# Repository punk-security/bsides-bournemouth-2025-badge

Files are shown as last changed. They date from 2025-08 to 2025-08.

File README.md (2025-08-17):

# BSides Bournemouth (2025) Skull badge

This badge uses UV full colour silk, and we ordered them from JLCPCB using EasyEDA. The PCB was built first with AutoCAD EAGLE, then exported.

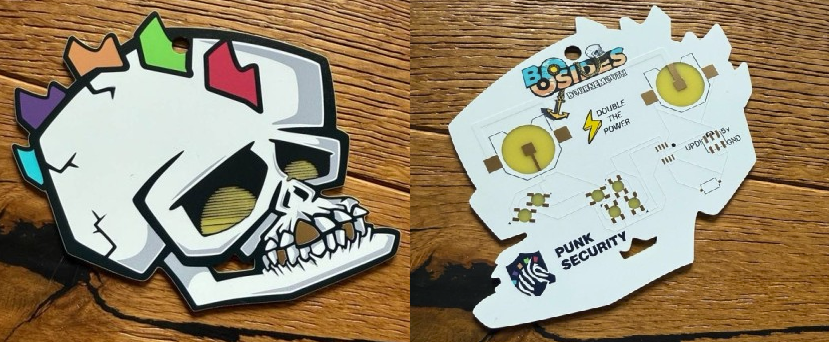
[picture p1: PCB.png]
PCB


Lots of things in this repo:

- eagle-files: all the stuff you need to tinker and modify the PCB
- gerber-files.zip: the file you can upload to JLCPCB and order your own badge, as is
- bsides-bournemouth-2025-badge.ino: the arduino code that powers the badge, which you can modify and flash via the SAO connector
- skull.svg: the original vector design for the badge
- skull.png: the silkscreen as ordered

## Bill Of Materials

You can see a parts list on DigiKey [here](https://www.digikey.co.uk/en/mylists/list/Z9CH9C1GM3). This is the list for the BSIDES Cheltenham 2024 badge, but it is the same bits.

Essentially its:

* ATTINY402 microcontroller
* Button - any surface mount button fitting the footprint will work
* CR2032 battery clip x 2 - surface mount not through hole
* Neopixel 5050 addressable LED - Definitely get the right version of these

## Eagle designs and ordering your own badge

We've uploaded the AutoCAD EAGLE schematic and board design!  You will probably have to do some tweaks to get it working as they're not designed to be standalone exports.

We've also uploaded the gerber_files.zip.  Take this to JLCPCB and you can order your own exact copies of the board :)

## Writing and flashing code!

We use [MegaTinyCore](https://github.com/SpenceKonde/megaTinyCore) for the arduino interface for ATTINY4x2 chips.

Dev and flashing is done within the Arduino IDE ( < v2 ) using a jtag2updi interface, as discussed [here](https://github.com/SpenceKonde/AVR-Guidance/blob/master/UPDI/jtag2updi.md)

We use [these little usb sticks](https://amzn.eu/d/c0lx0wG), with a 4.7k resistor soldered between the Tx and Rx lines.  

### Installing MegaTinyCore dependencies

This board package can be installed via the board manager in arduino. The boards manager URL is:

`http://drazzy.com/package_drazzy.com_index.json`

1. File -> Preferences, enter the above URL in "Additional Boards Manager URLs"
2. Tools -> Boards -> Boards Manager...
3. Wait while the list loads (takes longer than one would expect, and refreshes several times).
4. Select "megaTinyCore by Spence Konde" and click "Install". For best results, choose the most recent version.

### Setting up the IDE

1. Open the file **bsides-cheltenham-2024-badge.ino** in arduino
2. Select tools > Board > megaTinyCore > ATtiny412/402/212/202
3. Select tools > Chip > ATtiny402
4. Select tools > Clock > 8Mhz internal *(we get power issues otherwise)*
5. Select tools > Programmer > SerialUPDI SLOW
6. Select tools > Port > ( pick your COM port)

### Flashing firmware
1. Connect the 3v3 pin to 3v on your usb (maybe wedge it in the battery clip)
2. Connect GND to GND
3. Connect UPDI to the RxD port
4. Click Upload button

## How to solder?

Make sure to line up the dot on the attiny402 with the dot on the board.

Make sure to line the corner of the LED with the cutout with the triable on the board

*It's much easier if you hold the component in place with one hand, and then solder one pad. Now you can solder the rest of the pads with one hand*

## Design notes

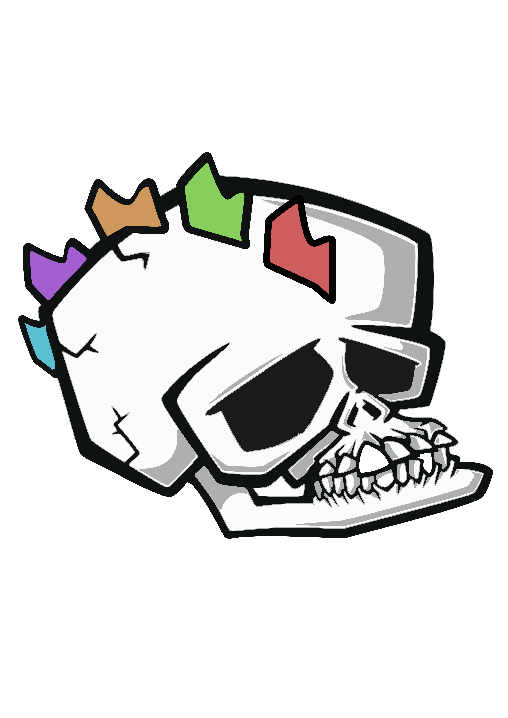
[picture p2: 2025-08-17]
skull.png

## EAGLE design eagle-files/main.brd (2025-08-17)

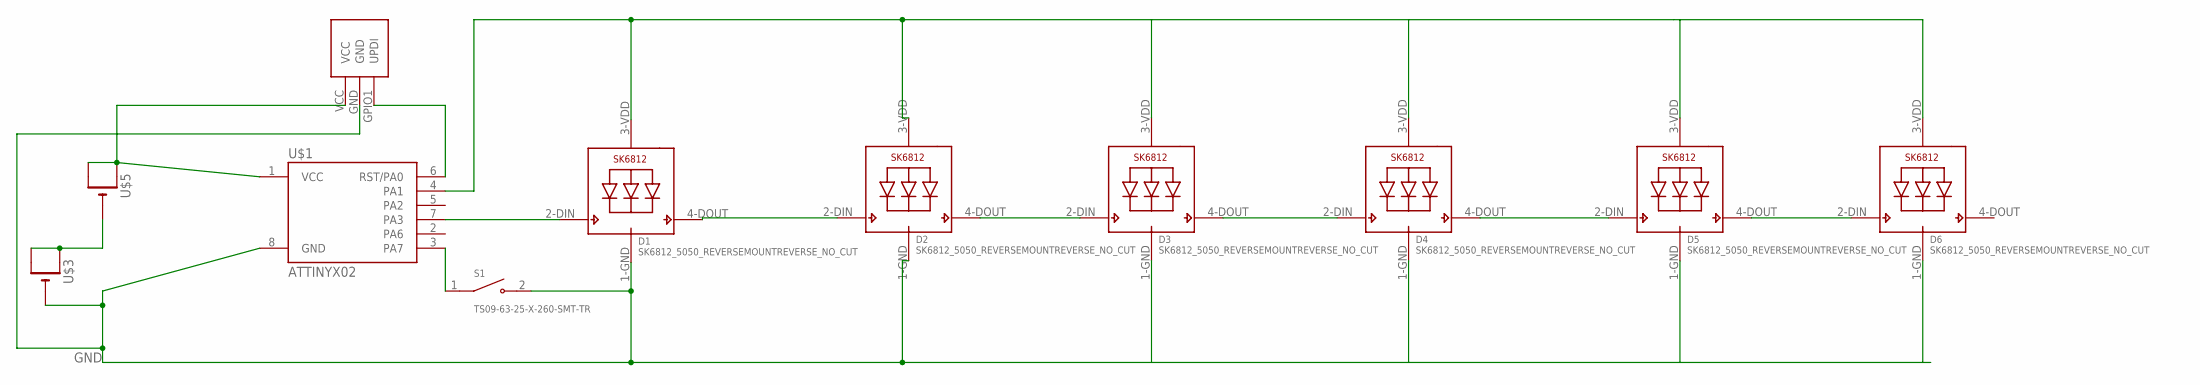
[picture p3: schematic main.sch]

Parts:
D1, D2, D3, D4, D5, D6: SK6812_5050_REVERSEMOUNTREVERSE_NO_CUT; SK6812_REVERSE_NO_CUT
S1: TS09-63-25-X-260-SMT-TR; SW_TS09-63-25-X-260-SMT-TR
U$1: ATTINYX02; SOIC08_JEDEC_150MIL
U$2: SAO; SAO_SMD
U$3, U$5: CR2032SMT; CR2032-SMD

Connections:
GND: D1.1-GND (GND), D2.1-GND (GND), D3.1-GND (GND), D4.1-GND (GND), D5.1-GND (GND), D6.1-GND (GND), S1.2, U$1.8 (GND), U$2.GND, U$3.-
unnamed: D1.4-DOUT (DO), D2.2-DIN (DI)
unnamed: D1.2-DIN (DI), U$1.7 (PA3)
unnamed: D3.4-DOUT (DO), D4.2-DIN (DI)
unnamed: D2.4-DOUT (DO), D3.2-DIN (DI)
unnamed: S1.1, U$1.3 (PA7)
unnamed: D4.4-DOUT (DO), D5.2-DIN (DI)
unnamed: D5.4-DOUT (DO), D6.2-DIN (DI)
unnamed: U$3.+$1 (+), U$3.+$2 (+1), U$5.-
unnamed: U$1.6 (RST/PA0), U$2.GPIO1 (UPDI)
VCC1: U$1.1 (VCC), U$2.VCC, U$5.+$1 (+), U$5.+$2 (+1)
VDD1: D1.3-VDD (VDD), D2.3-VDD (VDD), D3.3-VDD (VDD), D4.3-VDD (VDD), D5.3-VDD (VDD), D6.3-VDD (VDD), U$1.4 (PA1)

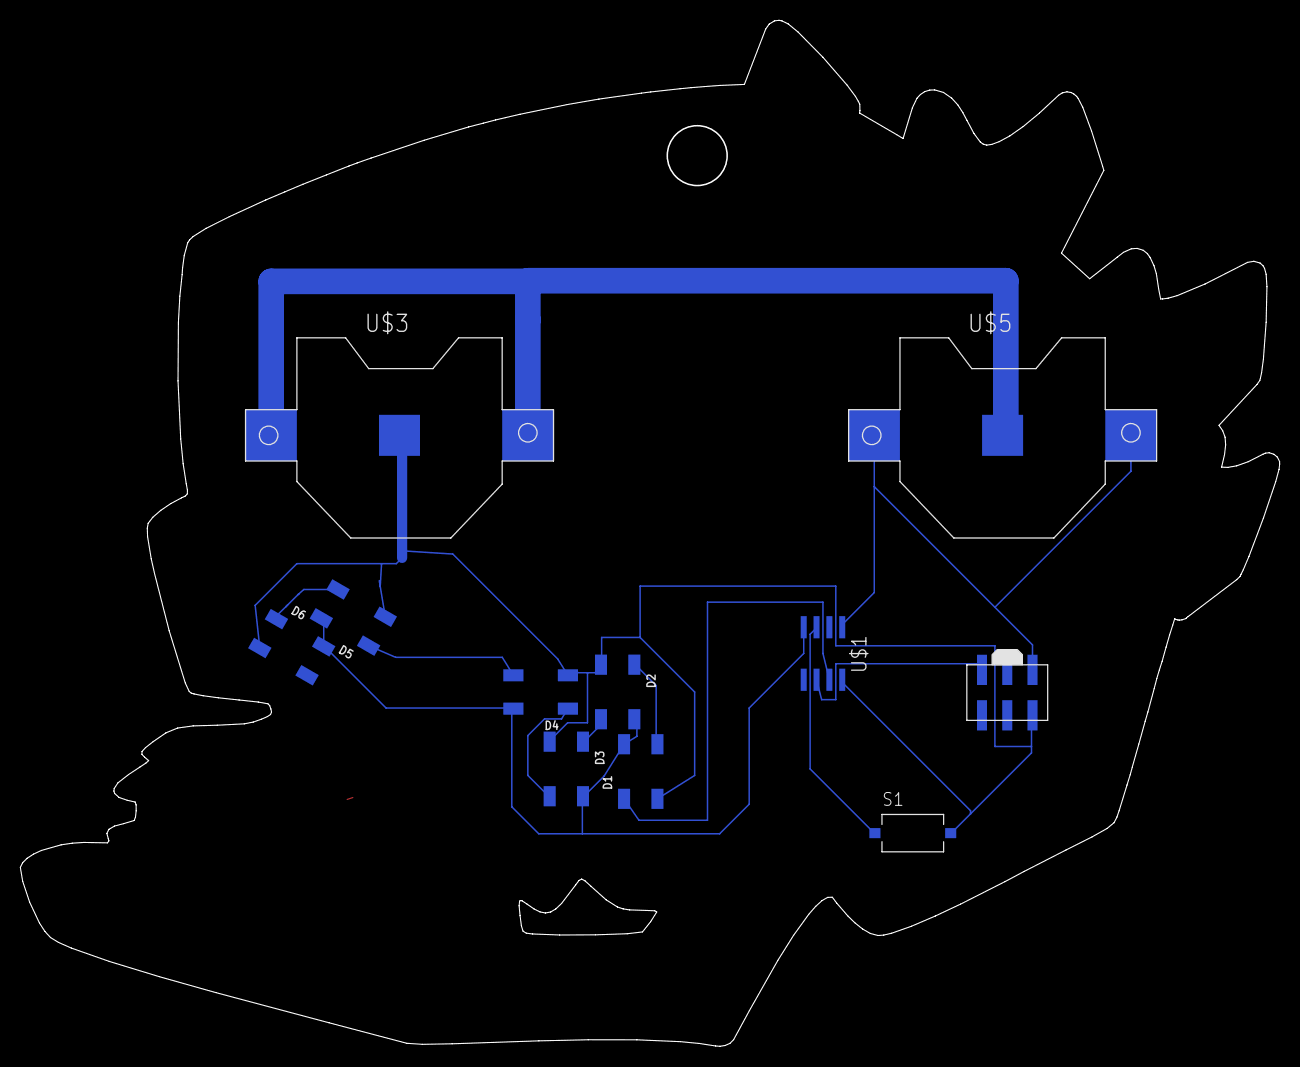
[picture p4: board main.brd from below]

Board: 2 copper layers, 124.6 x 101.5 mm, 11 parts (11 on the bottom side), 12 nets.

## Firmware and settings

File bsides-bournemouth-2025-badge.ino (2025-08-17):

#include <avr/io.h>-
#include <avr/pgmspace.h>
#include <EEPROM.h>
#include <tinyNeoPixel_Static.h>

// FEEL FREE TO TWEAK

// Wake time
# define WAKE_TIME_MS 300000
// Colours

#define OFF 0,0,0
#define BLUE 0,0,255
#define PINK 6,0,4
#define OLIVE 2,2,0
#define YELLOWGREEN 20,30,20
#define RED 50,0,0
#define ORANGE 50,30,0
#define YELLOW 30,50,0
#define GREEN 0,50,0
#define BLUE 0,0,255
#define PURPLE 10,0,128
#define BB_BLUE 0,100,255
#define BB_SAND 194,178,128

// DONT CHANGE
#define NUMLEDS 6
#define MORSE_CODE_PIN PIN_PA7
// LED positions
#define LT 1
#define LL 0
#define LB 2
#define LR 3
#define RL 4
#define RR 5

byte pixels[NUMLEDS * 3];
tinyNeoPixel strip = tinyNeoPixel(NUMLEDS, PIN_PA3, NEO_GRB, pixels);

uint16_t time_pin_low(uint16_t max_ms)
{
  // blocking for up to max_ms
  if (digitalRead(MORSE_CODE_PIN) == HIGH)
  {
    return(0);
  }
  delay(50); //debounce-
  uint16_t t = 50;
  while(digitalRead(MORSE_CODE_PIN) == LOW)
  {
    delay(5);
    t = t + 5;
    if ( t > max_ms )
      return(max_ms);
  }
  return(t);
}

void setAllPixels(int r, int g, int b, bool show = false)
{
  for (int i = 0; i < NUMLEDS; i++) 
  {
    strip.setPixelColor(i,r,g,b);
  }
  if(show)
    strip.show();
}

int fill(int x, int r, int g, int b)
{
  int step = x % 6;
  switch(step)
  {
    case 0:
      strip.setPixelColor(RR, r,g,b);
      break;
    case 1:
      strip.setPixelColor(RL, r,g,b);
      break;
    case 2:
      strip.setPixelColor(LR, r,g,b);
      break;
    case 3:
      strip.setPixelColor(LB, r,g,b);
      break;
    case 4:
      strip.setPixelColor(LT, r,g,b);
      break;
    case 5:
      strip.setPixelColor(LL, r,g,b);
      break;
    default:
      break;
  }
  strip.show();
  return 100;
}

#include <avr/sleep.h>

void sleep()
{
  set_sleep_mode(SLEEP_MODE_PWR_DOWN);
  PORTA.PIN7CTRL = PORT_PULLUPEN_bm | PORT_ISC_LEVEL_gc; // enable pullup and interrupt
  digitalWrite(PIN_PA1, LOW); // turn off LED power rail
  sleep_enable();
  sleep_cpu();
  // sleep resumes here
  PORTA.PIN7CTRL = PORT_PULLUPEN_bm; // renable pullup but no interrupt
  digitalWrite(PIN_PA1, HIGH);  // turn on LED power rail
}

ISR(PORTA_PORT_vect) {
  PORTA.INTFLAGS = PORT_INT7_bm; // Clear Pin 7 interrupt flag otherwise keep coming back here
}

uint8_t state;

void setup()
{
  // Power save
  // http://www.technoblogy.com/show?2RA3
  // https://github.com/SpenceKonde/megaTinyCore/blob/master/megaavr/extras/PowerSave.md
  ADC0.CTRLA &= ~ADC_ENABLE_bm; // Disable ADC
  pinMode(PIN_PA1, OUTPUT);
  pinMode(PIN_PA2, OUTPUT);
  pinMode(PIN_PA6, OUTPUT);
  // UPDI does not need setting (PA0)

  // Pin setup
  pinMode(PIN_PA3, OUTPUT);
  pinMode(PIN_PA7, INPUT_PULLUP);
  digitalWrite(PIN_PA1, HIGH);

  
  state = EEPROM.read(0);
  if (state == B11111111)
  {
    EEPROM.update(0, 0);
    state = EEPROM.read(0);
  }
  
}

int circle(int x, int r, int g, int b)
{
  int i = x % 7;
  setAllPixels(OFF);
  switch(i) {
   case 0:
    strip.setPixelColor(LB, OFF);
    strip.setPixelColor(LL, r, g, b);
    break;
   case 1:
    strip.setPixelColor(LL, OFF);
    strip.setPixelColor(LT, r, g, b);
    break;
   case 2:
    strip.setPixelColor(LT, OFF);
    strip.setPixelColor(RL, r, g, b);
    break;
   case 3:
    strip.setPixelColor(RL, OFF);
    strip.setPixelColor(RR, r, g, b);
    break;
   case 4:
    strip.setPixelColor(RR, OFF);
    strip.setPixelColor(RL, r, g, b);
    break;
   case 5:
    strip.setPixelColor(RL, OFF);
    strip.setPixelColor(LR, r, g, b);
    break;
   case 6:
    strip.setPixelColor(LR, OFF);
    strip.setPixelColor(LB, r, g, b);
    break;
  }
  strip.show();
  return 100;
}

int random_cycle(int n)
{
  int i = random(0,6);
  switch(i) {
   case 0:
    setAllPixels(RED,true);
    break;
   case 1:
    setAllPixels(ORANGE,true);
    break;
   case 2:
    setAllPixels(YELLOW,true);
    break;
   case 3:
    setAllPixels(GREEN,true);
    break;
   case 4:
    setAllPixels(BLUE,true);
    break;
   case 5:
    setAllPixels(PURPLE,true);
    break;
  }
  return 150;
}

int cycle(int n)
{
  int i = n % 5;
  switch(i) {
   case 0:
    setAllPixels(RED,true);
    break;
   case 1:
    setAllPixels(GREEN,true);
    break;
   case 2:
    setAllPixels(ORANGE,true);
    break;
   case 3:
    setAllPixels(PURPLE,true);
    break;
   case 4:
    setAllPixels(BLUE,true);
    break;
  }
  return 300;
}

int bournemouth(int n)
{
  int i = n % 9;
  setAllPixels(BB_SAND);

  if (i == 1)
  {
    strip.setPixelColor(LT, BB_BLUE);
  }
    else if (i == 2)
  {
    strip.setPixelColor(LT, BB_BLUE);
    strip.setPixelColor(LL, BB_BLUE);
    strip.setPixelColor(LR, BB_BLUE);
  }
    else if (i == 3 || i == 4)
  {
    strip.setPixelColor(LT, BB_BLUE);
    strip.setPixelColor(LL, BB_BLUE);
    strip.setPixelColor(LR, BB_BLUE);
    strip.setPixelColor(RL, BB_BLUE);
    strip.setPixelColor(LB, BB_BLUE);
  }
      else if (i == 5)
  {
    strip.setPixelColor(LT, BB_BLUE);
    strip.setPixelColor(LL, BB_BLUE);
    strip.setPixelColor(LR, BB_BLUE);
    strip.setPixelColor(RL, BB_BLUE);
  }
  else if (i == 6)
  {
    strip.setPixelColor(LT, BB_BLUE);
    strip.setPixelColor(LL, BB_BLUE);
  }
  else
  {
    strip.setPixelColor(LT, BB_BLUE);
  }
  strip.show();
  return 500;
}

int green(int n)
{
  int i = n % 4;
  setAllPixels(OFF);

  if (i == 0)
  {
    strip.setPixelColor(LT, GREEN);
    strip.setPixelColor(LL, GREEN);
  }
    else if (i == 1)
  {
    strip.setPixelColor(LR, GREEN);
    strip.setPixelColor(LB, GREEN);
  }
    else if (i == 2)
  {
    strip.setPixelColor(RL, GREEN);
  }
      else if (i == 3)
  {
    strip.setPixelColor(RR, GREEN);
  }
  strip.show();
  return 100;
}

int police2(int n)
{
  int i = n % 2;
  setAllPixels(RED);

  if (i == 0)
  {
    strip.setPixelColor(LT, BLUE);
    strip.setPixelColor(LL, BLUE);
    strip.setPixelColor(RL, BLUE);
  }
    else if (i == 1)
  {
    strip.setPixelColor(LR, BLUE);
    strip.setPixelColor(LB, BLUE);
    strip.setPixelColor(RR, BLUE);
  }
  strip.show();
  return 200;
}

int fill_cycle(int x)
{
  int color_step = x % 31;
  switch (color_step)
  {
    case 0 ... 5:
      return fill(color_step,RED);
      break;    
    case 6 ... 11:
      return fill(color_step,GREEN);
      break;
    case 12 ... 17:
      return fill(color_step,ORANGE);
      break;
    case 18 ... 23:
      return fill(color_step,PURPLE);
      break;
    case 24 ... 29:
      return fill(color_step,BLUE);
      break;  
  }
  return 0;
}

int punk(int x)
{
  int color_step = (x % 11) + 1;
  strip.setPixelColor(LL,BLUE);
  strip.setPixelColor(LT,PURPLE);
  strip.setPixelColor(LB,PURPLE);
  strip.setPixelColor(LR,ORANGE);
  strip.setPixelColor(RL,GREEN);
  strip.setPixelColor(RR,RED);
  strip.setBrightness(200 + (48 / color_step));
  strip.show();
  return 10;
}


int fireeye(int x)
{
  setAllPixels(OFF);
  int color_step = (x % 11) + 1;
  strip.setPixelColor(LB,random(0,100), random(0,10), 0);
  strip.setPixelColor(RR,random(0,100), random(0,10), 0);
  strip.show();
  return 10;
}


void loop()
{
  int mode = 0;
  int interval;
  uint16_t button_low_time = 0;
  uint32_t total_interval = 0;
  strip.begin();
  int i = 0;
  while(true)
  {
    strip.setBrightness(255);
    if ( mode == 0 )
    {
      interval = bournemouth(i);
    }
    else if ( mode == 1 )
    {
      interval = green(i);
    }
    else if ( mode == 2 )
    {
      interval = fill_cycle(i);
    }
    else if ( mode == 3 )
    {
      interval = fireeye(i);
    }
    else if ( mode == 4 )
    {
      interval = cycle(i);
    }
    else if ( mode == 5 )
    {
      interval = punk(i);
    }
    else if ( mode == 6 )
    {
      interval = police2(i);
    }
    else if ( mode == 7 )
    {
      interval = circle(i, 255,0,0);
    }
    else
    {
      mode = (mode +1) % 8;
      continue;
    }
    i++;
    // This section breaks down the sleep interval to catch button presses
    total_interval = total_interval + interval;
    while(interval > 0)
    {
      delay(10);
      interval = interval - 10;
      button_low_time = time_pin_low(4000);
      if (button_low_time > 200)
      {
       /*
       * MAIN MENU
       * NO PRESS = CONTINUE
       * SHORT PRESS = CHANGE FLASHY MODE
       * LONG PRESS = SLEEP
       */
        if (button_low_time == 4000)
        {
            digitalWrite(PIN_PA1, LOW);
            while(digitalRead(MORSE_CODE_PIN) == LOW)
              { delay(5); }
          delay(40);
          sleep();
        }
        else
        {
          mode = (mode +1) % 8;
        }
        // reset timer
        i = 0;
        total_interval = 0;
      }

    }
    // At the end of each interval, see if we need to sleep
    if (total_interval > WAKE_TIME_MS)
    {
      total_interval = 0;
      i = 0;
      sleep();
    }
  }
}
